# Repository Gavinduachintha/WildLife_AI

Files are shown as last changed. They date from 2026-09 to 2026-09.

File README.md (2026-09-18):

<div align="center">

# WildLife AI

</div>
ChatGPT Image Sep 19, 2026, 12_58_54 AM

## Introduction

WildLife AI is a prototype edge-computing system for monitoring remote forest environments. It uses computer vision on a Raspberry Pi 5 to identify objects or activities of interest, obtains the monitoring node's geographic position through a GPS module, and transmits a compact alert over a LoRa link.

The receiving station is based on a Raspberry Pi Pico 2. It receives the alert and presents the detected object, confidence value, geographic coordinates, and communication status on an IPS display. Detection is performed locally so that the system does not require continuous internet access or transmission of camera footage to a cloud service.

## Project Objectives

The system is intended to:

- detect selected objects in camera frames;
- associate detections with GPS coordinates;
- transmit detection data over a long-range, low-bandwidth radio link; and
- present received alerts at a separate monitoring station.

The project is intended for research and prototyping. It must not be treated as a certified safety, security, or emergency-response system.

## System Architecture

The system consists of two nodes.

The following diagram illustrates the connection between the remote monitoring node and the receiving station.

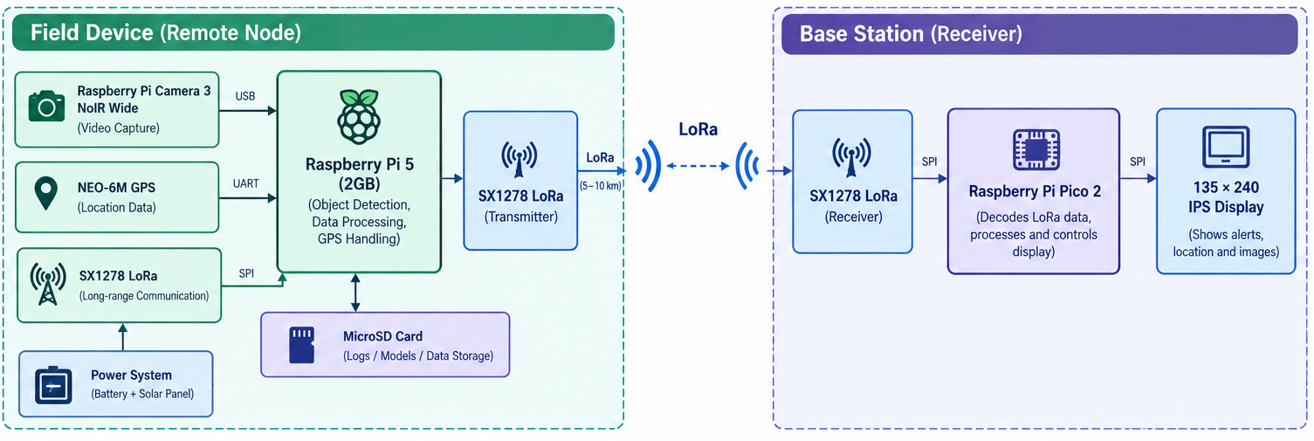
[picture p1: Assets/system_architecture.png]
WildLife AI system architecture


_Figure 1. System architecture of the WildLife AI monitoring and receiving nodes._

### Remote Monitoring Node

The remote node uses the following components:

- Raspberry Pi 5 (2 GB) for application execution and AI inference;
- Raspberry Pi Camera 3 NoIR for image acquisition;
- an object-detection model, currently represented by `yolov8n.pt`;
- NEO-6M GPS module for position acquisition; and
- SX1278 LoRa module for alert transmission.

The remote node captures images, performs inference, reads the GPS position when required, creates a detection message, and transmits the message through LoRa.

### Receiving Node

The receiving node uses the following components:

- Raspberry Pi Pico 2;
- SX1278 LoRa module; and
- 135 x 240 colour IPS display.

The receiving node obtains LoRa packets, processes the received fields, and updates the display with the available detection and status information.

## Detection and Communication Workflow

The expected operational sequence is:

1. The camera provides an image frame.
2. The Raspberry Pi 5 processes the frame and runs object detection.
3. If an object of interest is identified, the application obtains the current GPS position.
4. The application creates a detection message containing the object type, confidence value, latitude, longitude, and alert status.
5. The SX1278 transmitter sends the message over the LoRa link.
6. The Raspberry Pi Pico 2 receives and processes the message.
7. The receiving station displays the received information.

An example message is:

```text
OBJECT=HUMAN
CONF=0.91
LAT=XX.XXXX
LON=XX.XXXX
STATUS=ALERT
```

The exact message format and radio settings are defined by the implementation in the source files and receiver firmware.

## Hardware Requirements

| Component | Purpose |
| --- | --- |
| Raspberry Pi 5 | Edge processing and application execution |
| Raspberry Pi Camera 3 NoIR | Image acquisition |
| SX1278 LoRa modules | Wireless communication between the two nodes |
| NEO-6M GPS module | Geographic position acquisition |
| Raspberry Pi Pico 2 | Receiving station controller |
| 135 x 240 IPS display | Alert and status presentation |

The camera must be connected to the Raspberry Pi 5 through the CSI interface. The GPS module must be connected to the UART interface configured by the application. The LoRa modules must use compatible frequency, spreading factor, bandwidth, coding rate, sync word, and other radio parameters.

## Software Requirements

The project contains Python programs for the Raspberry Pi and an Arduino-compatible receiver program for the Raspberry Pi Pico 2. Python dependencies are listed in `requirements.txt`.

The following software is required for the Raspberry Pi implementation:

- Python 3;
- the packages listed in `requirements.txt`;
- Raspberry Pi camera support, including `rpicam-hello`; and
- access to the connected camera, GPS, and LoRa hardware.

The receiver requires the libraries and board configuration appropriate for the selected Raspberry Pi Pico 2 display and LoRa hardware.

## Installation

Clone the repository and enter its directory:

```bash
git clone https://github.com/Gavinduachintha/WildLife-AI.git
cd WildLife-AI
```

Create and activate a Python virtual environment:

```bash
python3 -m venv .venv
source .venv/bin/activate
```

Install the Python dependencies:

```bash
pip install -r requirements.txt
```

On Windows, activate the virtual environment with:

```powershell
.venv\Scripts\Activate.ps1
```

The hardware-dependent portions of the project are intended to run on the configured Raspberry Pi system. The virtual environment alone does not provide access to the camera, GPS, or LoRa hardware.

## Hardware Verification

Verify that the Raspberry Pi camera is available before starting the application:

```bash
rpicam-hello
```

Verify that the GPS module is connected to the configured UART interface and that it provides serial position data. Verify that both LoRa modules use matching radio settings and that the antenna and power configuration are suitable for the deployment.

## Running the Application

Start the main application on the Raspberry Pi 5 with:

```bash
python main.py
```

The application initializes the camera, GPS, LoRa interface, and detection model before entering the detection loop. The appropriate receiver firmware must be loaded onto the Raspberry Pi Pico 2 for alerts to be displayed.

## Repository Structure

The current repository contains:

```text
WildLifeAI/
├── Assets/
│   └── system_architecture.png
├── PCB Project/
│   ├── LoRa Tracker.kicad_pcb
│   ├── LoRa Tracker.kicad_pro
│   └── LoRa Tracker.kicad_sch
├── Receiver/
│   └── lora_rx_final_working_with_display.ino
├── cam2.py
├── cam3.py
├── camera1.py
├── detect.py
├── detect1.py
├── Final.py
├── gpsTest.py
├── main.py
├── requirements.txt
├── yolov8n.pt
└── README.md
```

Some Python files are experimental or provide separate hardware tests. `main.py` is the documented application entry point. The receiver firmware is located in `Receiver/`, and the KiCad design files are located in `PCB Project/`.

## Communication Range

The project uses a target communication range of approximately 5 to 10 km. This is not a guaranteed operating distance. Actual performance depends on antenna configuration, terrain, vegetation, obstacles, transmit power, frequency, spreading factor, bandwidth, coding rate, and receiver sensitivity.

## Limitations

Detection performance depends on the model, training data, lighting, camera position, object distance and size, occlusion, and environmental conditions. The system may produce false positives or false negatives.

LoRa is a low-bandwidth communication method and is appropriate for compact detection messages rather than continuous video. Communication reliability and range must be tested under the conditions of the intended deployment.

The project is a prototype. Hardware compatibility, electrical safety, radio compliance, data protection, and operational reliability must be evaluated before any field deployment.

## Author

Gavindu Achintha

## Contact

For project-related questions or contributions, contact the author through [GitHub](https://github.com/Gavinduachintha).

## License

The project license has not been specified in the current repository.

---

<p align="center">
	<strong>WildLife AI</strong><br>
	Edge monitoring for remote environments<br>
	<a href="https://github.com/Gavinduachintha">Gavindu Achintha on GitHub</a>
</p>

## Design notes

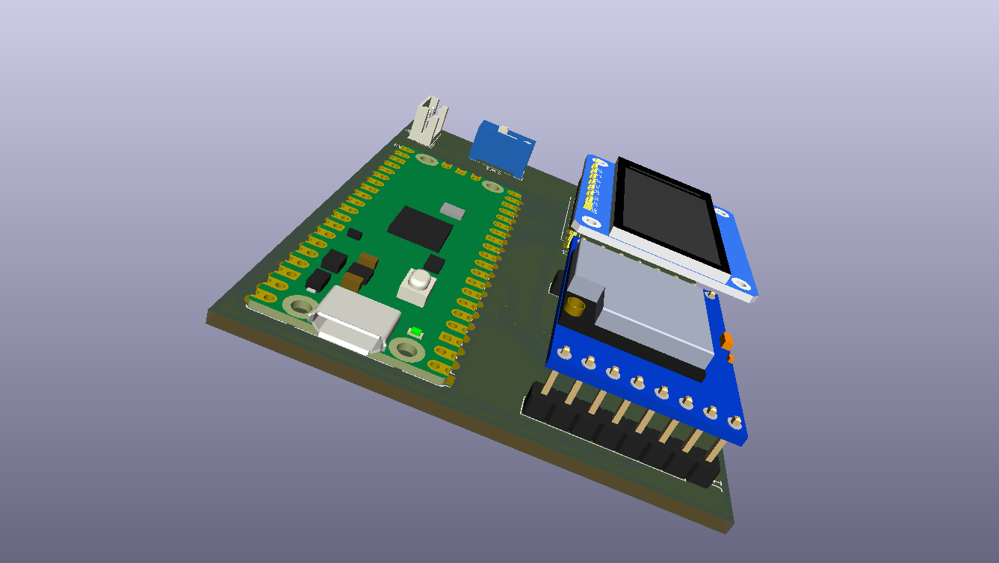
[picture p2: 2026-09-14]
PCB Project/LoRa Tracker Side.png

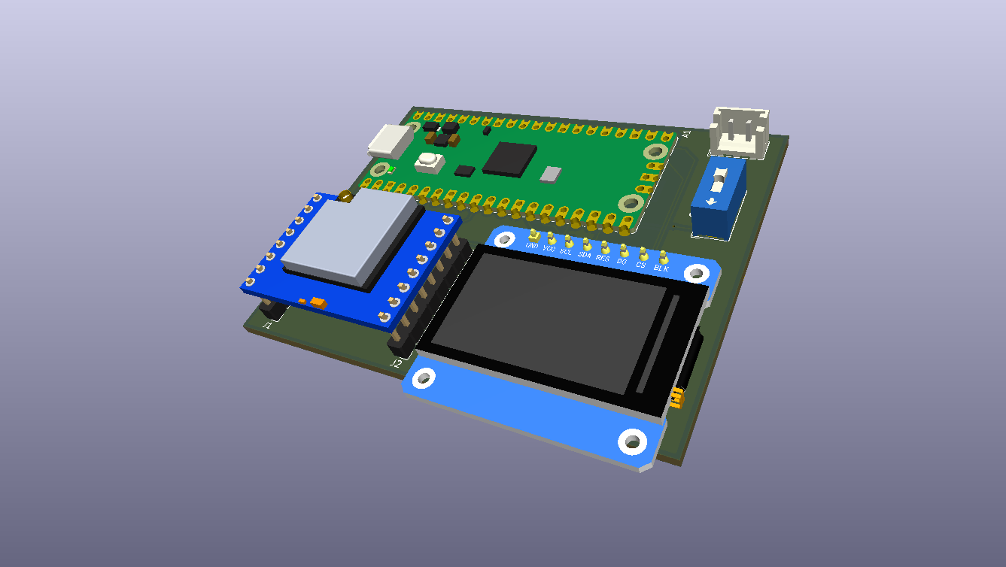
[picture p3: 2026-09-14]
PCB Project/LoRa Tracker.png

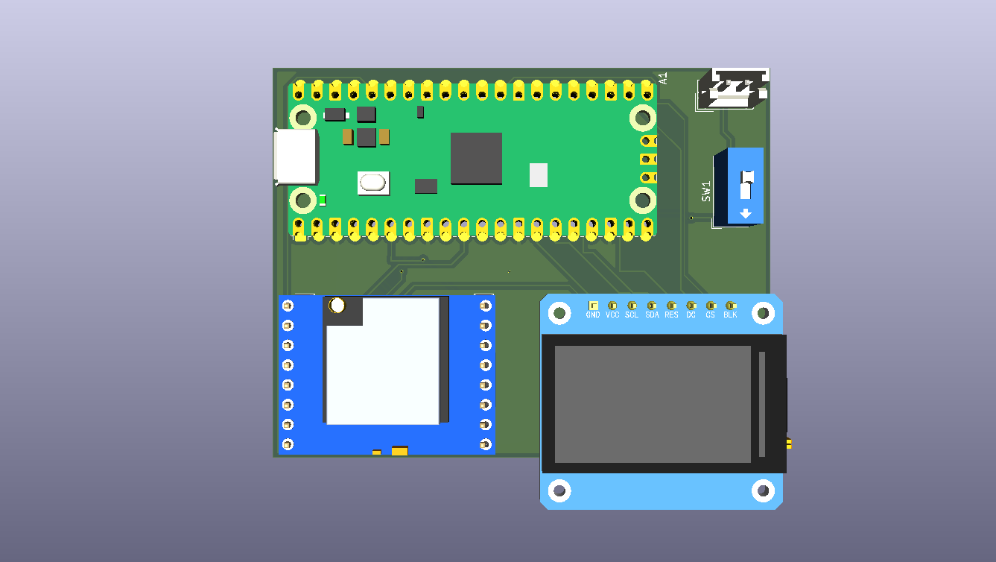
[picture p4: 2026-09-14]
PCB Project/LoRa Tracker Front.png

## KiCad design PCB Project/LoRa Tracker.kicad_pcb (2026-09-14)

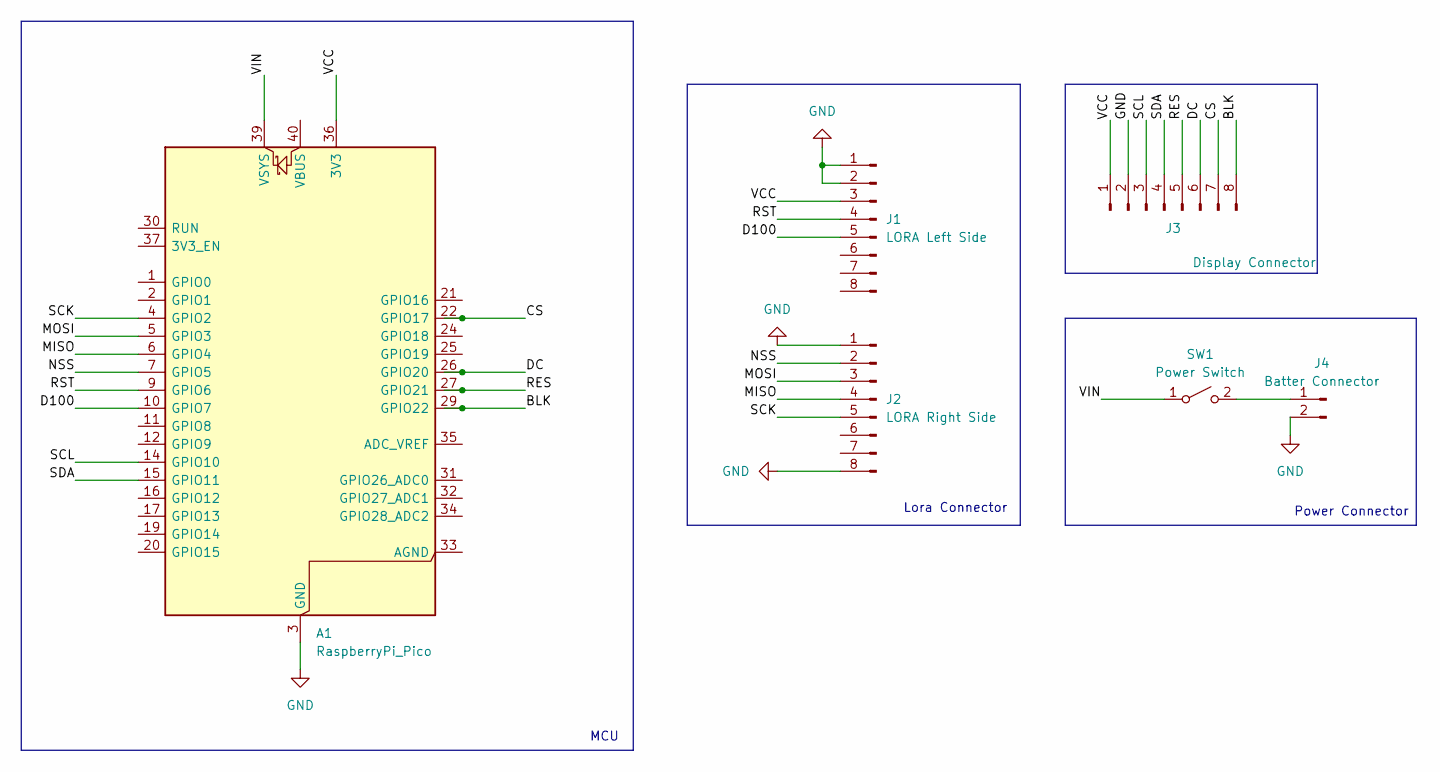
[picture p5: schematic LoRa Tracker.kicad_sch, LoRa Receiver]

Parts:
A1: RaspberryPi_Pico; RaspberryPi_Pico_Common_Unspecified
J1: LORA Left Side; PinHeader_1x08_P2.54mm_Vertical
J2: LORA Right Side; PinHeader_1x08_P2.54mm_Vertical
J3: Display Connector; PinHeader_1x08_P2.54mm_Vertical
J4: Batter Connector; JST_EH_B2B-EH-A_1x02_P2.50mm_Vertical
SW1: Power Switch; SW_DIP_SPSTx01_Slide_9.78x4.72mm_W7.62mm_P2.54mm

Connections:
/BLK: A1.29 (GPIO22), J3.8
/CS: A1.22 (GPIO17), J3.7
/D100: A1.10 (GPIO7), J1.5
/DC: A1.26 (GPIO20), J3.6
/MISO: A1.6 (GPIO4), J2.4
/MOSI: A1.5 (GPIO3), J2.3
/NSS: A1.7 (GPIO5), J2.2
/RES: A1.27 (GPIO21), J3.5
/RST: A1.9 (GPIO6), J1.4
/SCK: A1.4 (GPIO2), J2.5
/SCL: A1.14 (GPIO10), J3.3
/SDA: A1.15 (GPIO11), J3.4
/VCC: A1.36 (3V3), J1.3, J3.1
/VIN: A1.39 (VSYS), SW1.1 (A)
GND: A1.3 (GND), A1.8 (GND), A1.13 (GND), A1.18 (GND), A1.23 (GND), A1.28 (GND), A1.38 (GND), J1.1, J1.2, J2.1, J2.8, J3.2, J4.2
unnamed: J4.1, SW1.2 (B)

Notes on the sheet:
MCU
Lora Connector
Power Connector

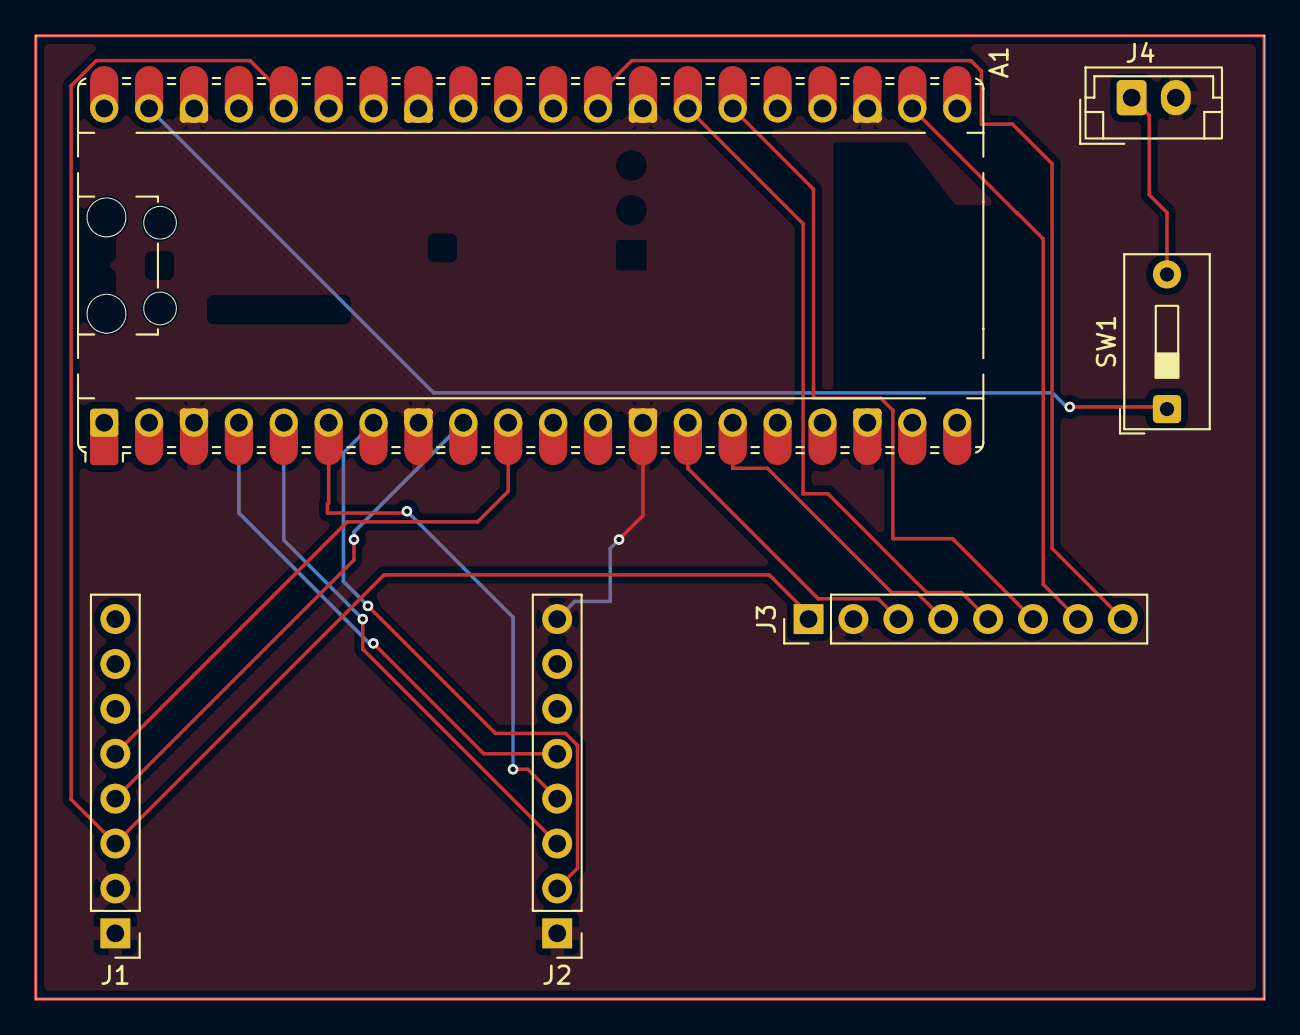
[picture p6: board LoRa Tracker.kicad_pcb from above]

Board: 2 copper layers, 69.5 x 54.5 mm, 6 parts (0 on the bottom side), 16 nets.

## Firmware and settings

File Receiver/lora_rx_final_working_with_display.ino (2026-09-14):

#include <SPI.h>
#include <Adafruit_GFX.h>
#include <Adafruit_ST7789.h>

// =====================================================
// SX1278 LORA PINS
// =====================================================
#define LORA_SCK   2
#define LORA_MOSI  3
#define LORA_MISO  4
#define LORA_CS    5
#define LORA_RST   6
#define LORA_DIO0  7

// =====================================================
// ST7789 DISPLAY PINS
// =====================================================
#define TFT_SCK    10
#define TFT_MOSI   11
#define TFT_CS     17
#define TFT_DC     20
#define TFT_RST    21
#define TFT_BLK    22

#define TFT_WIDTH  240
#define TFT_HEIGHT 135

// =====================================================
// SX1278 REGISTERS
// =====================================================
#define REG_FIFO              0x00
#define REG_OP_MODE           0x01
#define REG_FRF_MSB           0x06
#define REG_FRF_MID           0x07
#define REG_FRF_LSB           0x08
#define REG_FIFO_RX_CURRENT   0x10
#define REG_IRQ_FLAGS         0x12
#define REG_RX_NB_BYTES       0x13
#define REG_FIFO_ADDR_PTR     0x0D
#define REG_MODEM_CONFIG1     0x1D
#define REG_MODEM_CONFIG2     0x1E
#define REG_MODEM_CONFIG3     0x26
#define REG_PREAMBLE_MSB      0x20
#define REG_PREAMBLE_LSB      0x21
#define REG_SYNC_WORD         0x39
#define REG_VERSION           0x42

#define LONG_RANGE_MODE       0x80
#define MODE_SLEEP            0x00
#define MODE_STDBY            0x01
#define MODE_RX_CONTINUOUS    0x05

#define IRQ_RX_DONE           0x40
#define IRQ_PAYLOAD_CRC_ERROR 0x20

// =====================================================
// LORA SPI
// =====================================================
SPISettings loraSPI(1000000, MSBFIRST, SPI_MODE0);

// =====================================================
// DISPLAY (SPI1)
// =====================================================
SPIClassRP2040 displaySPI(spi1, 12, TFT_CS, TFT_SCK, TFT_MOSI);

Adafruit_ST7789 tft(&displaySPI, TFT_CS, TFT_DC, TFT_RST);

// =====================================================
// GLOBAL VARIABLES
// =====================================================
uint32_t packetCount = 0;
String lastMessage = "Waiting for message...";
String latitude = "--";
String longitude = "--";
bool hasLocation = false;

// =====================================================
// LORA REGISTER FUNCTIONS
// =====================================================
void writeRegister(uint8_t reg, uint8_t value) {
  SPI.beginTransaction(loraSPI);
  digitalWrite(LORA_CS, LOW);
  SPI.transfer(reg | 0x80);
  SPI.transfer(value);
  digitalWrite(LORA_CS, HIGH);
  SPI.endTransaction();
}

uint8_t readRegister(uint8_t reg) {
  SPI.beginTransaction(loraSPI);
  digitalWrite(LORA_CS, LOW);
  SPI.transfer(reg & 0x7F);
  uint8_t value = SPI.transfer(0x00);
  digitalWrite(LORA_CS, HIGH);
  SPI.endTransaction();
  return value;
}

void resetLoRa() {
  digitalWrite(LORA_RST, LOW);
  delay(10);
  digitalWrite(LORA_RST, HIGH);
  delay(10);
}

void setFrequency(long frequency) {
  uint32_t frf = (uint32_t)((frequency / 32000000.0) * 524288);
  writeRegister(REG_FRF_MSB, (frf >> 16) & 0xFF);
  writeRegister(REG_FRF_MID, (frf >> 8) & 0xFF);
  writeRegister(REG_FRF_LSB, frf & 0xFF);
}

// =====================================================
// DISPLAY FUNCTIONS
// =====================================================
void drawHeader() {
  tft.fillRect(0, 0, 240, 26, ST77XX_BLUE);
  tft.setTextColor(ST77XX_WHITE);
  tft.setTextSize(2);
  tft.setCursor(8, 5);
  tft.print("LORA RECEIVER");
  tft.fillCircle(226, 13, 5, ST77XX_GREEN);
}

void drawStatusBar() {
  tft.fillRect(0, 117, 240, 18, ST77XX_BLACK);
  tft.setTextSize(1);
  tft.setTextColor(ST77XX_WHITE);
  tft.setCursor(5, 122);
  tft.print("433MHz  SF7  BW125");
  tft.setCursor(175, 122);
  tft.print("#");
  tft.print(packetCount);
}

void displayStartup() {
  tft.fillScreen(ST77XX_BLACK);
  tft.setTextColor(ST77XX_CYAN);
  tft.setTextSize(2);
  tft.setCursor(40, 25);
  tft.print("LORA");
  tft.setCursor(30, 50);
  tft.print("RECEIVER");

  tft.setTextColor(ST77XX_WHITE);
  tft.setTextSize(1);
  tft.setCursor(45, 80);
  tft.print("SX1278  |  433 MHz");
  tft.setCursor(60, 100);
  tft.print("Initializing...");
  delay(1500);

  tft.fillScreen(ST77XX_BLACK);
  drawHeader();
  tft.setTextColor(ST77XX_YELLOW);
  tft.setTextSize(1);
  tft.setCursor(25, 55);
  tft.print("Waiting for LoRa message...");
  drawStatusBar();
}

void displayMessage(String message) {
  tft.fillScreen(ST77XX_BLACK);
  drawHeader();

  // ---- Parse location from message ----
  hasLocation = false;
  latitude = "--";
  longitude = "--";

  int latIndex = message.indexOf("LAT:");
  int lonIndex = message.indexOf("LON:");

  if (latIndex != -1 && lonIndex != -1) {
    // Extract Latitude
    int latStart = latIndex + 4;
    int latEnd = message.indexOf(' ', latStart);
    if (latEnd == -1) latEnd = message.length();
    latitude = message.substring(latStart, latEnd);
    latitude.trim();

    // Extract Longitude
    int lonStart = lonIndex + 4;
    int lonEnd = message.indexOf(' ', lonStart);
    if (lonEnd == -1) lonEnd = message.length();
    longitude = message.substring(lonStart, lonEnd);
    longitude.trim();

    hasLocation = true;
  }

  // ---- Main Title ----
  tft.setTextColor(ST77XX_CYAN);
  tft.setTextSize(1);
  tft.setCursor(8, 32);
  tft.print("ALERT");

  tft.setTextColor(ST77XX_WHITE);
  tft.setTextSize(2);
  tft.setCursor(8, 45);
  tft.print("PERSON DETECTED");

  // ---- Location Section ----
  tft.setTextColor(ST77XX_YELLOW);
  tft.setTextSize(1);
  tft.setCursor(8, 72);
  tft.print("LOCATION");

  tft.setTextColor(ST77XX_WHITE);
  tft.setTextSize(1);

  if (hasLocation) {
    tft.setCursor(8, 88);
    tft.print("Lat: ");
    tft.print(latitude);

    tft.setCursor(8, 102);
    tft.print("Lon: ");
    tft.print(longitude);
  } else {
    tft.setCursor(8, 90);
    tft.setTextColor(ST77XX_RED);
    tft.print("GPS: NO FIX");
  }

  drawStatusBar();
}

void displayCRCError() {
  tft.fillScreen(ST77XX_BLACK);
  drawHeader();

  tft.setTextColor(ST77XX_RED);
  tft.setTextSize(2);
  tft.setCursor(50, 50);
  tft.print("CRC ERROR");

  tft.setTextColor(ST77XX_WHITE);
  tft.setTextSize(1);
  tft.setCursor(30, 85);
  tft.print("Corrupted packet received");
  drawStatusBar();
  delay(800);
}

// =====================================================
// LORA SETUP
// =====================================================
void setupLoRa() {
  resetLoRa();

  uint8_t version = readRegister(REG_VERSION);
  Serial.print("SX1278 Version: 0x");
  Serial.println(version, HEX);

  writeRegister(REG_OP_MODE, LONG_RANGE_MODE | MODE_SLEEP);
  delay(10);
  writeRegister(REG_OP_MODE, LONG_RANGE_MODE | MODE_STDBY);

  setFrequency(433000000);

  writeRegister(REG_MODEM_CONFIG1, 0x72);  // BW=125kHz, CR=4/5
  writeRegister(REG_MODEM_CONFIG2, 0x74);  // SF7 + CRC
  writeRegister(REG_MODEM_CONFIG3, 0x04);
  writeRegister(REG_PREAMBLE_MSB, 0x00);
  writeRegister(REG_PREAMBLE_LSB, 0x08);
  writeRegister(REG_SYNC_WORD, 0x12);
  writeRegister(REG_IRQ_FLAGS, 0xFF);

  writeRegister(REG_OP_MODE, LONG_RANGE_MODE | MODE_RX_CONTINUOUS);
  Serial.println("LoRa receiver ready.");
}

// =====================================================
// RECEIVE PACKET
// =====================================================
void receivePacket() {
  uint8_t irq = readRegister(REG_IRQ_FLAGS);

  if (!(irq & IRQ_RX_DONE)) return;

  if (irq & IRQ_PAYLOAD_CRC_ERROR) {
    Serial.println("CRC ERROR");
    displayCRCError();
    writeRegister(REG_IRQ_FLAGS, 0xFF);
    return;
  }

  uint8_t length = readRegister(REG_RX_NB_BYTES);
  uint8_t fifoAddress = readRegister(REG_FIFO_RX_CURRENT);
  writeRegister(REG_FIFO_ADDR_PTR, fifoAddress);

  String message = "";
  Serial.print("Received: ");

  for (uint8_t i = 0; i < length; i++) {
    uint8_t data = readRegister(REG_FIFO);
    Serial.write(data);
    message += (char)data;
  }
  Serial.println();

  packetCount++;
  lastMessage = message;

  displayMessage(message);          // Updated display function

  writeRegister(REG_IRQ_FLAGS, 0xFF);
}

// =====================================================
// SETUP
// =====================================================
void setup() {
  Serial.begin(115200);
  delay(1500);

  // LoRa pins
  pinMode(LORA_CS, OUTPUT);
  digitalWrite(LORA_CS, HIGH);
  pinMode(LORA_RST, OUTPUT);
  digitalWrite(LORA_RST, HIGH);
  pinMode(LORA_DIO0, INPUT);

  // LoRa SPI (SPI0)
  SPI.setSCK(LORA_SCK);
  SPI.setTX(LORA_MOSI);
  SPI.setRX(LORA_MISO);
  SPI.begin();

  // Display backlight
  pinMode(TFT_BLK, OUTPUT);
  digitalWrite(TFT_BLK, HIGH);

  // Display SPI (SPI1)
  displaySPI.setSCK(TFT_SCK);
  displaySPI.setTX(TFT_MOSI);
  displaySPI.begin();

  // Display init
  tft.init(135, 240);
  tft.setRotation(3);               // Landscape 240x135
  tft.fillScreen(ST77XX_BLACK);

  displayStartup();
  setupLoRa();
}

// =====================================================
// MAIN LOOP
// =====================================================
void loop() {
  receivePacket();
  delay(10);
}

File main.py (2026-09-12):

"""This is the complete project file that includes real time 
    detection, LoRa message sending and the GPS locating
"""
#!/usr/bin/env python3
import spidev
import lgpio
import time
import serial
import pynmea2
import threading
import cv2
from ultralytics import YOLO
from picamera2 import Picamera2

# -----------------------------
# GPIO Pins (LoRa)
# -----------------------------
RESET = 25
DIO0 = 4

# -----------------------------
# SX1278 Registers
# -----------------------------
FREQUENCY = 433E6
REG_FIFO = 0x00
REG_OP_MODE = 0x01
REG_FRF_MSB = 0x06
REG_FRF_MID = 0x07
REG_FRF_LSB = 0x08
REG_PA_CONFIG = 0x09
REG_FIFO_ADDR_PTR = 0x0D
REG_FIFO_TX_BASE_ADDR = 0x0E
REG_IRQ_FLAGS = 0x12
REG_MODEM_CONFIG1 = 0x1D
REG_MODEM_CONFIG2 = 0x1E
REG_PREAMBLE_MSB = 0x20
REG_PREAMBLE_LSB = 0x21
REG_PAYLOAD_LENGTH = 0x22
REG_MODEM_CONFIG3 = 0x26
REG_SYNC_WORD = 0x39
REG_VERSION = 0x42

MODE_LONG_RANGE = 0x80
MODE_SLEEP = 0x00
MODE_STDBY = 0x01
MODE_TX = 0x03
IRQ_TX_DONE = 0x08

# -----------------------------
# Global GPS data
# -----------------------------
gps_data = {
    "lat": None,
    "lon": None,
    "alt": None,
    "valid": False
}

# -----------------------------
# SPI Setup
# -----------------------------
spi = spidev.SpiDev()
spi.open(0, 0)
spi.max_speed_hz = 5000000
spi.mode = 0

# -----------------------------
# GPIO Setup
# -----------------------------
h = None
try:
    h = lgpio.gpiochip_open(4)
    lgpio.gpio_claim_output(h, RESET, 1)
    lgpio.gpio_claim_input(h, DIO0)
except:
    try:
        if h is not None:
            lgpio.gpiochip_close(h)
    except:
        pass
    h = lgpio.gpiochip_open(0)
    lgpio.gpio_claim_output(h, RESET, 1)
    lgpio.gpio_claim_input(h, DIO0)

# -----------------------------
# LoRa Functions
# -----------------------------
def write_reg(reg, value):
    spi.xfer2([reg | 0x80, value])

def read_reg(reg):
    return spi.xfer2([reg & 0x7F, 0x00])[1]

def reset_lora():
    lgpio.gpio_write(h, RESET, 0)
    time.sleep(0.01)
    lgpio.gpio_write(h, RESET, 1)
    time.sleep(0.01)

def set_frequency(freq):
    frf = int((freq / 32e6) * (2 ** 19))
    write_reg(REG_FRF_MSB, (frf >> 16) & 0xFF)
    write_reg(REG_FRF_MID, (frf >> 8) & 0xFF)
    write_reg(REG_FRF_LSB, frf & 0xFF)

def lora_init():
    reset_lora()
    version = read_reg(REG_VERSION)
    print("SX1278 version:", hex(version))
    if version != 0x12:
        print("WARNING: Unexpected SX1278 version")

    write_reg(REG_OP_MODE, MODE_LONG_RANGE | MODE_SLEEP)
    time.sleep(0.01)
    write_reg(REG_OP_MODE, MODE_LONG_RANGE | MODE_STDBY)

    set_frequency(FREQUENCY)
    write_reg(REG_FIFO_TX_BASE_ADDR, 0x00)
    write_reg(REG_PA_CONFIG, 0x8F)
    write_reg(REG_MODEM_CONFIG1, 0x72)
    write_reg(REG_MODEM_CONFIG2, 0x74)
    write_reg(REG_MODEM_CONFIG3, 0x04)
    write_reg(REG_PREAMBLE_MSB, 0x00)
    write_reg(REG_PREAMBLE_LSB, 0x08)
    write_reg(REG_SYNC_WORD, 0x12)
    write_reg(REG_IRQ_FLAGS, 0xFF)
    print("LoRa initialized")

def send(message):
    data = message.encode()
    if len(data) > 255:
        raise ValueError("Message too long")

    write_reg(REG_OP_MODE, MODE_LONG_RANGE | MODE_STDBY)
    write_reg(REG_FIFO_ADDR_PTR, 0x00)

    for byte in data:
        write_reg(REG_FIFO, byte)

    write_reg(REG_PAYLOAD_LENGTH, len(data))
    write_reg(REG_IRQ_FLAGS, 0xFF)
    write_reg(REG_OP_MODE, MODE_LONG_RANGE | MODE_TX)

    print("Sending:", message)

    timeout = time.time() + 5
    while time.time() < timeout:
        irq = read_reg(REG_IRQ_FLAGS)
        if irq & IRQ_TX_DONE:
            write_reg(REG_IRQ_FLAGS, IRQ_TX_DONE)
            print("TX complete")
            return True
        time.sleep(0.001)

    print("TX timeout")
    return False

# -----------------------------
# GPS Reader Thread
# -----------------------------
def gps_reader():
    global gps_data
    try:
        ser = serial.Serial("/dev/serial0", baudrate=9600, timeout=1)
        print("GPS serial opened on /dev/serial0")
    except Exception as e:
        print("Failed to open GPS serial:", e)
        return

    while True:
        try:
            line = ser.readline().decode("ascii", errors="replace").strip()
            if line.startswith(("$GPGGA", "$GNGGA")):
                msg = pynmea2.parse(line)
                if msg.latitude and msg.longitude:
                    gps_data["lat"] = msg.latitude
                    gps_data["lon"] = msg.longitude
                    gps_data["alt"] = msg.altitude
                    gps_data["valid"] = True
        except Exception:
            pass
        time.sleep(0.1)

# -----------------------------
# MAIN
# -----------------------------
try:
    # Start GPS thread
    gps_thread = threading.Thread(target=gps_reader, daemon=True)
    gps_thread.start()

    # Initialize LoRa
    lora_init()

    # Initialize YOLO + Camera
    print("Loading YOLO model...")
    model = YOLO("yolov8n.pt")

    picam2 = Picamera2()
    picam2.configure(picam2.create_preview_configuration(main={"size": (640, 480)}))
    picam2.start()
    time.sleep(1)

    print("System ready. Looking for persons...")
    print("Press 'q' in the window to quit")

    last_send_time = 0
    COOLDOWN = 8          # seconds between LoRa messages

    while True:
        frame = picam2.capture_array()
        frame = cv2.cvtColor(frame, cv2.COLOR_BGRA2RGB)

        results = model(frame, imgsz=320, verbose=False)

        # Check for person (class 0)
        person_detected = False
        for r in results:
            if r.boxes is not None:
                for cls in r.boxes.cls:
                    if int(cls) == 0:
                        person_detected = True
                        break
            if person_detected:
                break

        # Send LoRa message if person detected
        current_time = time.time()
        if person_detected and (current_time - last_send_time) > COOLDOWN:
            if gps_data["valid"]:
				#7.464030333462776, 80.01888618205285
                #msg = f"PERSON DETECTED | LAT:{gps_data['lat']:.6f} LON:{gps_data['lon']:.6f}"
                msg = f"PERSON DETECTED | LAT:{7.464030333462776:.6f} LON:{80.01888618205285:.6f}"
            else:
                msg = "PERSON DETECTED | GPS: NO FIX"

            send(msg)
            last_send_time = current_time

        # Show annotated frame
        annotated = results[0].plot()

        # Optional: show GPS status on screen
        status = "GPS: OK" if gps_data["valid"] else "GPS: NO FIX"
        cv2.putText(annotated, status, (10, 30), cv2.FONT_HERSHEY_SIMPLEX, 0.7, (0, 255, 0) if gps_data["valid"] else (0, 0, 255), 2)

        cv2.imshow("YOLO + LoRa + GPS", annotated)

        if cv2.waitKey(1) & 0xFF == ord('q'):
            break

except KeyboardInterrupt:
    print("\nStopping...")
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

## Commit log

2026-09-12 feat: Add LoRa communication with person detection using YOLO
    - Initialize SX1278 LoRa module with SPI and GPIO control for wireless messaging
    - Implement YOLO object detection pipeline using YOLOv8 nano model on Raspberry Pi camera
    - Add person detection logic with LoRa transmission on detection events
    - Include cooldown mechanism to prevent message flooding (5 second interval)
    - Create multiple camera test utilities for development and debugging
    - Pre-train YOLOv8 nano model checkpoint for inference optimization
    - Integrate Picamera2 for native Raspberry Pi 5 camera capture with configurable resolution
    - Add proper resource cleanup with exception handling for GPIO, SPI, and camera teardown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
    [Final.py, cam2.py, camera1.py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]
2026-09-12 docs: Enhance README with improved visual hierarchy and formatting
    - Add centered header with badges for Edge AI, Raspberry Pi, and LoRa
    - Reorganize features section into interactive table layout with emoji grouping
    - Convert monitored objects list to table format for better visual presentation
    - Add visual dividers and section spacing for improved readability
    - Enhance system architecture ASCII diagram with centered alignment
    - Restructure hardware components table with emoji indicators and centered alignment
    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
2026-09-14 Add the PCB project files for the LoRa receiver
    [LoRa Tracker.kicad_pcb, LoRa Tracker.kicad_sch]
